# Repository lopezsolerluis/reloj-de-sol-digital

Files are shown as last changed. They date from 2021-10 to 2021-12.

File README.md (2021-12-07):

# reloj de sol digital

En el que damos cuenta de las discusiones, epifanías y callejones sin salida de Antonia y Cecilia.

## Un posible juego de STLs

Para quien quiera imprimir una posible versión del reloj sin necesidad de usar OpenSCAD, Cecilia y Antonia me permitieron ofrecer la que pueden encontrar en este mismo repositorio en su correspondiente carpeta.

La base y el cabezal son diseño de **Ramiro Gabriel Arambarri**.

###  _Non est ad astra mollis e terris via_

La frase que adorna el reloj es de Séneca el joven, y también nos fue acercada por Ramiro. No puedo imaginar una leyenda más apropiada para nuestro curso... :)

### Armado

Las imágenes creo que despejan cualquier duda acerca del armado del reloj.

Las tolerancias de los orificios y encastres fueron pensadas para mi impresora 3D; es posible que quien confíe en los STLs ofrecidos deba apelar a los servicios de las limas y los pegamentos. ;)

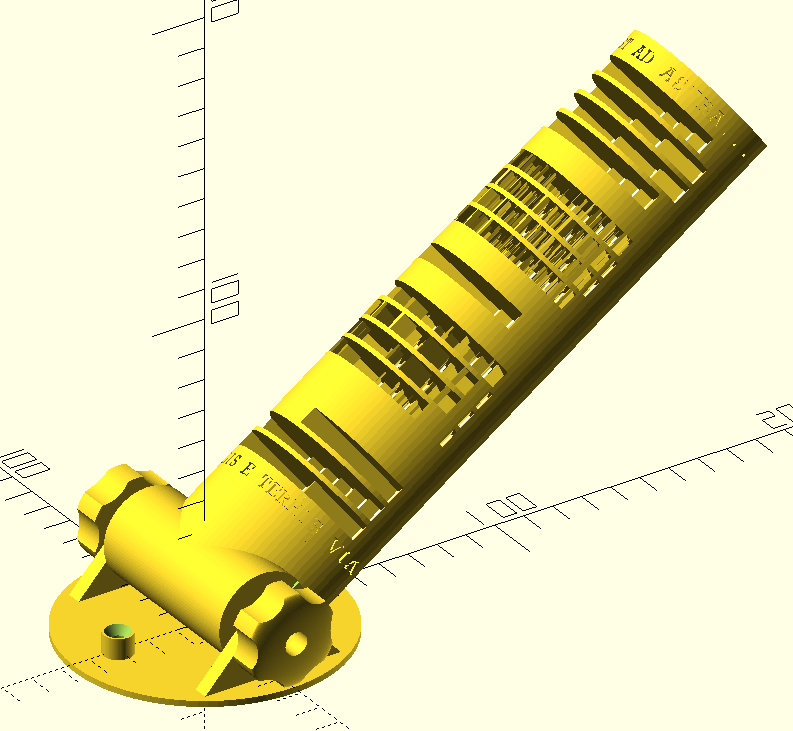
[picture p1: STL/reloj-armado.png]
Reloj Armado

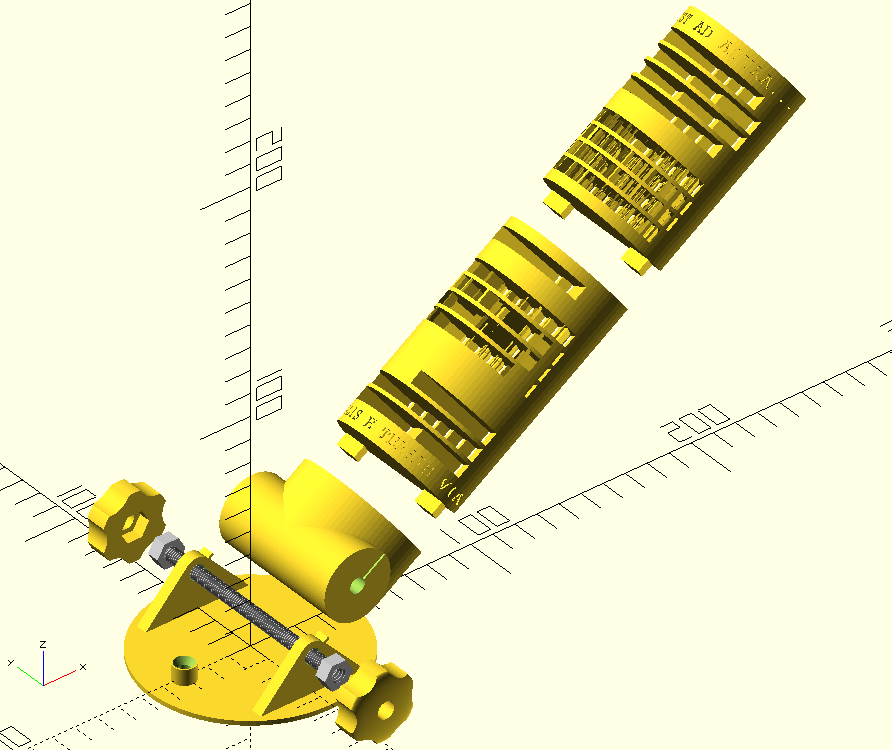
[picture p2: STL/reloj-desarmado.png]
Reloj Desarmado


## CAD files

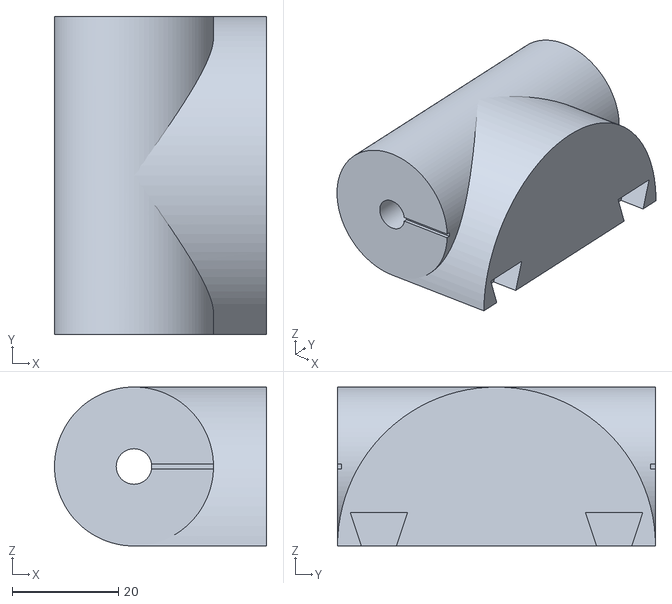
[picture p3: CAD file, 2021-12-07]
STL/cabezal.stl
40.0 x 60.0 x 30.0

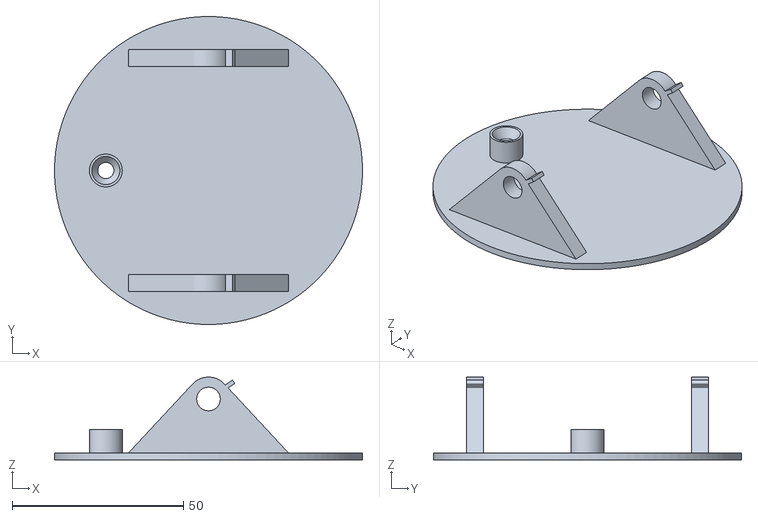
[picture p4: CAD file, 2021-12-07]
STL/base.stl
90.0 x 90.0 x 24.2

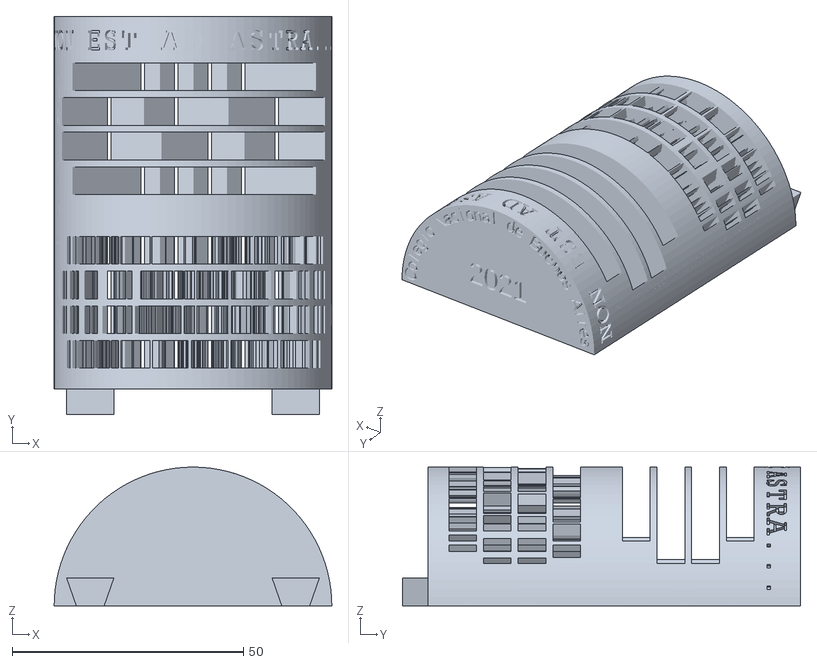
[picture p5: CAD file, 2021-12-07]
STL/reloj-minutos.stl
60.0 x 86.0 x 30.0

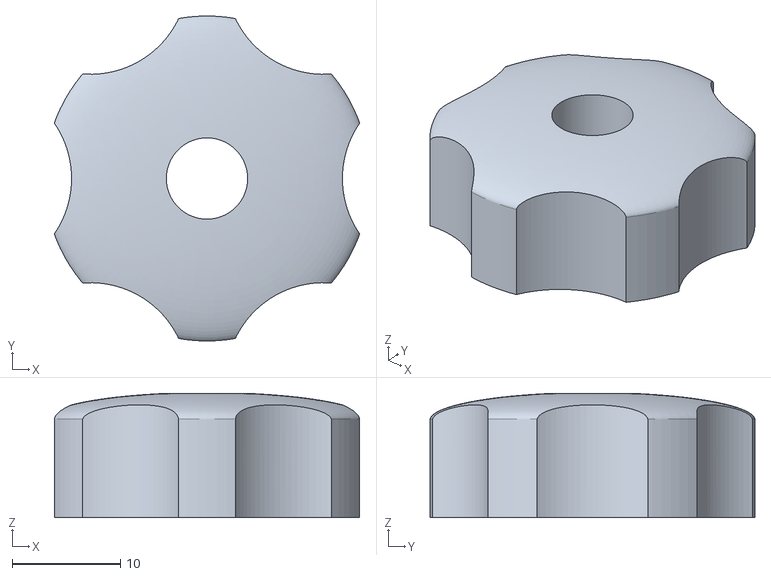
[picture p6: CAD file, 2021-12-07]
STL/perillax2.stl
28.2 x 30.0 x 11.5

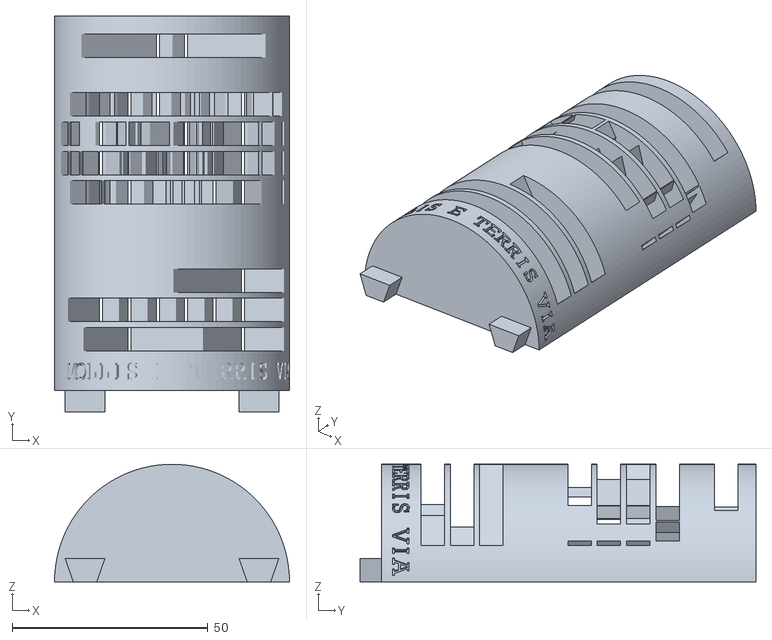
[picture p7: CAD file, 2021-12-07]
STL/reloj-horas.stl
60.0 x 101.0 x 30.0

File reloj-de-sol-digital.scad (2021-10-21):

$fn=100;

module semicilindro(h,r,center=false){
  difference(){
    cylinder(h=h,r=r,center=center);
    translate([-2*r,0,-h])
      cube([4*r,2*r,3*h]);
  }
}

hemisferio="sur";
texto_1 = "Ab Revolutionibus Astri...";
texto_2 = "...Girum Orbis Noscimus";
alto_pixel = .75;
ancho_pixel = 6;
delta_alto  = 6.5;
delta_ancho = 1.5;
borde = 10;
radio_semicilindro = 30;
H = radio_semicilindro+10;
largo_reloj = 21*ancho_pixel + 20*delta_ancho + 2*borde;

function alfa_sur(hora)=270-15*hora; 
function alfa_norte(hora)=15*hora-90;

function alfa(hora)=
  hemisferio=="sur" ? alfa_sur(hora) : alfa_norte(hora);

function truncate(n)=
  n<0 ? ceil(n) : floor(n);

// p es la posicion del digito a obtener: 
// 0 para las unidades, 1 para las decenas, etc.
function n_a_digito(n,p)= 
  truncate(n/pow(10,p))%10;

module haz_de_sol(alfa1,alfa2){
  alfa_min=min(alfa1,alfa2);
  alfa_max=max(alfa1,alfa2);
  D1=H/tan(alfa_min);
  D2=H/tan(alfa_max);
  vertices=[[-alto_pixel/2,0],
            [D2-alto_pixel/2,H],
            [D1+alto_pixel/2,H],
            [alto_pixel/2,0]];
  rotate ([90,0,0])
    linear_extrude(ancho_pixel,center=true)
      polygon(vertices);
}

digitos = [
[[0, 1 ,1, 0], // cero
 [1, 0, 0, 1],
 [1, 0, 1, 1],
 [1, 1, 0, 1],
 [1, 0, 0, 1],
 [0, 1, 1, 0]],
[[0, 1, 0 ,0], // uno
 [1, 1, 0, 0],
 [0, 1, 0, 0],
 [0, 1, 0, 0],
 [0, 1, 0, 0],
 [1, 1, 1, 0]],
[[0, 1 ,1, 0], // dos
 [1, 0, 0, 1],
 [0, 0, 0, 1],
 [0, 1, 1, 0],
 [1, 0, 0, 0],
 [1, 1, 1, 1]],
[[0, 1 ,1, 0],  // tres
 [1, 0, 0, 1],
 [0, 0, 1, 1],
 [0, 0, 0, 1],
 [1, 0, 0, 1],
 [0, 1, 1, 0]],
[[1, 0 ,0, 1],  //cuatro
 [1, 0, 0, 1],
 [1, 0, 0, 1],
 [1, 1, 1, 1],
 [0, 0, 0, 1],
 [0, 0, 0, 1]],
[[1, 1 ,1, 1],  // cinco
 [1, 0, 0, 0],
 [1, 1, 1, 0],
 [0, 0, 0, 1],
 [0, 0, 0, 1],
 [1, 1, 1, 0]],
[[0, 1 ,1, 0],  // seis
 [1, 0, 0, 0],
 [1, 1, 1, 0],
 [1, 0, 0, 1],
 [1, 0, 0, 1],
 [0, 1, 1, 0]],
[[1, 1 ,1, 0],  // siete
 [0, 0, 1, 0],
 [0, 1, 0, 0],
 [0, 1, 0, 0],
 [0, 1, 0, 0],
 [0, 1, 0, 0]],
[[0, 1 ,1, 0],  // ocho
 [1, 0, 0, 1],
 [0, 1, 1, 0],
 [1, 0, 0, 1],
 [1, 0, 0, 1],
 [0, 1, 1, 0]],
[[0, 1 ,1, 0],  // nueve
 [1, 0, 0, 1],
 [1, 0, 0, 1],
 [0, 1, 1, 1],
 [0, 0, 0, 1],
 [0, 1, 1, 0]]];
 
module digito(numero,alfa1,alfa2){
  for(i=[0:5],j=[0:3]){
    digito=digitos[numero];
    if(digito[i][j]==1){
      x=(i-2.5)*(alto_pixel+delta_alto);
      y=(j-1.5)*(ancho_pixel+delta_ancho);
      translate([x,y,-0.01])
        haz_de_sol(alfa1,alfa2);
    }
  }
}

module hora_solar(horas, 
                  minutos){
  hora=horas+minutos/60;
  assert(hora>6 && hora<18,"La hora debe encontrarse entre las 6:00 y las 18:00.");
  alfa=alfa(hora);
  hora_decenas=n_a_digito(horas,1);
  hora_unidades=n_a_digito(horas,0);
  minuto_decenas=n_a_digito(minutos,1);
  minuto_unidades=n_a_digito(minutos,0);
                    
  delta_y=ancho_pixel+delta_ancho;
  // horas    
  if (hora_decenas != 0)
    translate([0,-8.5*delta_y,0])
      digito(hora_decenas,alfa,alfa);
  translate([0,-3.5*delta_y,0])
    digito(hora_unidades,alfa,alfa);  
  // minutos
  translate([0,3.5*delta_y,0])
    digito(minuto_decenas,alfa,alfa);
  translate([0,8.5*delta_y,0])
    digito(minuto_unidades,alfa,alfa);  
  // separador
  separador(alfa,alfa);
}

module separador(alfa1,alfa2){
  for(i=[-1,1])
    translate([i*0.5*(alto_pixel+delta_alto), 0, -.01])
      haz_de_sol(alfa1,alfa2);
}
 
module cuerpo(largo){
  rotate([-90,0,0])
    semicilindro(largo, radio_semicilindro, center=true);  
}

/* Reloj de Sol de algunas horas puntuales.
   'vector_horas' es un vector con las horas y minutos que el usuario desea mostrar; por ej.: [[12,00], [7,13], [16,23]] representa las 12:00, 7:13 y 16:23.
*/
module reloj_de_sol_discreto(vector_horas){
  difference(){
    cuerpo(largo_reloj);    
    for(hora_minutos=vector_horas){
      hora=hora_minutos[0];
      minutos=hora_minutos[1];
      hora_solar(hora,minutos);    
    }
  }
}

/*
  Reloj de Sol con las horas desde las 9:00 a las 15:10,
  en intervalos de 20 minutos.
*/
module reloj_de_sol_continuo(){
  delta_y=ancho_pixel+delta_ancho;
  difference(){
    cuerpo(largo_reloj);    
    // unidades de minuto
    translate([0,8.5*delta_y,0])
      digito(0,alfa(9),alfa(15+10/60));  
    // decenas de minuto
    translate([0,3.5*delta_y,0]){
      for(hora=[9:14],
          minutos=[0,20,40]){
            minuto_decenas=n_a_digito(minutos,1);
            digito(minuto_decenas,
                   alfa(hora+minutos/60),
                   alfa(hora+(minutos+10)/60));
            }
       digito(0,alfa(15),alfa(15+10/60));
       }                    
    // separador
    separador(alfa(9),alfa(15+10/60));      
    // unidades de hora       
    translate([0,-3.5*delta_y,0])
      for(hora=[9:15]){
        hora_unidades=n_a_digito(hora,0);
        digito(hora_unidades,
               alfa(hora),
               alfa(hora<15?hora+50/60:hora+10/60));
      }
    // decenas de hora
    translate([0,-8.5*delta_y,0])
      digito(1,alfa(10),alfa(15+10/60));    
  }
}

module texto_circular(texto, size, espesor, radio, angulo){
  n=len(texto)-1;
  delta_alfa=angulo/n;
  for(i=[0:n])
    rotate([0,0,delta_alfa*i-angulo/2])    
      translate([radio,0,0])
        rotate([90,0,90])
          linear_extrude(espesor)
            text(texto[i], size=size, font="DejaVu Sans:style=Book", halign="center");
}

/* Crea un reloj de Sol en función del valor de 'vector_horas'.
   Ver comentarios en los módulos
   'reloj_de_sol_continuo' y 'reloj_de_sol_discreto'.
*/
module reloj_de_sol(vector_horas){
  difference(){
    // Reloj
    if(vector_horas==undef)
      reloj_de_sol_continuo();
    else
      reloj_de_sol_discreto(vector_horas);
    // Textos
    translate([0,largo_reloj/2-borde+2.5,0])
      rotate([0,-90,-90])
        texto_circular(texto_1,5,2, radio_semicilindro-1.2,165);
    translate([0,-largo_reloj/2+2.5,0])
      rotate([0,-90,-90])
        texto_circular(texto_2,5,2, radio_semicilindro-1.9,165);
  }
}

reloj_de_sol();

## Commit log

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2021-06-10 Segunda versión del semicilindro: agregado del parámetro 'center'
    [reloj-de-sol-digital.scad]
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2021-06-23 Leve cambio a la primera versión del primer rayo de Sol
    [reloj-de-sol-digital.scad]
2021-07-01 Primera extrusión y rotación del rayo de Sol
    [reloj-de-sol-digital.scad]
2021-07-01 Versión de Antonia del rayo de Sol extrudido y rotado
    [reloj-de-sol-digital.scad]
2021-07-01 Primera versión del digito solar: la matriz completa
    [reloj-de-sol-digital.scad]
2021-07-01 Segunda versión del digito solar: la matriz centrada
    [reloj-de-sol-digital.scad]
2021-07-01 Tercera versión del digito solar: la matriz centrada usando un factor común
    [reloj-de-sol-digital.scad]
2021-07-01 Cuarta versión del digito solar: la matriz descendida 0.01 para evitar el error en el difference()
    [reloj-de-sol-digital.scad]
2021-08-09 La solución de Cecilia para la conformación de cada dígito.
    [reloj-de-sol-digital.scad]
2021-08-09 La manera de Cecilia, usando la sintaxis 'vector.x' y 'vector.y'.
    [reloj-de-sol-digital.scad]
2021-08-09 La solución de Antonia a la conformación de cada dígito.
    [reloj-de-sol-digital.scad]
2021-08-26 Las funciones que calculan el ángulo alfa en función de la hora del día, para ambos hemisferios terrestres.
    [reloj-de-sol-digital.scad]
2021-08-26 La función que calcula el ángulo alfa en función de la hora del día y el hemisferio terrestre elegido previamente por el usuario mediante una variable inicial.
    [reloj-de-sol-digital.scad]
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2021-08-31 El módulo 'hora_solar' ya sabe extraer los dígitos de la hora y los minutos.
    [reloj-de-sol-digital.scad]
2021-09-08 Primera versión del separador de horas y minutos
    [reloj-de-sol-digital.scad]
2021-09-08 Segunda versión del separador de horas y minutos
    [reloj-de-sol-digital.scad]
2021-09-08 Se añade un módulo que abstrae la idea del 'cuerpo' del reloj
    [reloj-de-sol-digital.scad]
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2021-09-08 Se modifica el módulo 'hora_solar' para que no muestre el '0' inicial en las horas previas a las 10:00.
    [reloj-de-sol-digital.scad]
2021-09-08 El separador pasa a formar parte del módulo 'hora_solar'.
    [reloj-de-sol-digital.scad]
2021-09-18 Se crea el módulo 'reloj-de-sol', y el largo del mismo está parametrizado.
    [reloj-de-sol-digital.scad]
2021-09-18 Primera versión (ingenua y fallida) del reloj de Sol, con todas las horas desde las 6:00 a las 18:00.
    [reloj-de-sol-digital.scad]
2021-09-18 Primer uso de 'assert' por parte de Cecilia, para evitar los ángulos extremos.
    [reloj-de-sol-digital.scad]
2021-09-18 Cecilia traslada el 'assert' dentro del módulo 'hora_solar'.
    [reloj-de-sol-digital.scad]
2021-09-18 Se impiden asimismo las horas fuera del intervalo entre las 6:00 y las 18:00.
    [reloj-de-sol-digital.scad]
2021-09-18 Cecilia confirma que el reloj aún funciona para las 12:00.
    [reloj-de-sol-digital.scad]
2021-09-24 Se cambió al alto de los pixeles de 2 a 1.6
    [reloj-de-sol-digital.scad]
2021-09-27 Versión de Cecilia de todas las horas separados por 20 minutos desde las 6:20 a las 17:40.
    [reloj-de-sol-digital.scad]
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2021-09-27 Reescritura de 'digito' para que trabaje con haz_de_sol.
    [reloj-de-sol-digital.scad]
2021-09-27 Primera modificación de hora_solar para que trabaje con haz_de_sol.
    [reloj-de-sol-digital.scad]
2021-09-27 Modificación del 'separador' para que trabaje con haz_de_sol.
    [reloj-de-sol-digital.scad]
2021-09-27 Modificación de hora_solar para que trabaje con el nuevo 'separador'.
    [reloj-de-sol-digital.scad]
2021-09-27 Antonia y Cecilia comprueban que todo sigue funcionando como antes luego de la refactorización.
    [reloj-de-sol-digital.scad]
2021-10-04 Se crea el módulo 'reloj_de_sol_discreto', capaz de mostrar horas particulares.
    [reloj-de-sol-digital.scad]
2021-10-04 Primera versión del 'reloj_de_sol_continuo', con las unidades de los minutos.
    [reloj-de-sol-digital.scad]
2021-10-04 Se corrige el bug del módulo 'haz_de_sol', referente al cruce de los ángulos del polígono que define el haz.
    [reloj-de-sol-digital.scad]
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2021-10-04 Se agregan las unidades de las horas a 'reloj_solar_continuo'.
    [reloj-de-sol-digital.scad]
2021-10-04 Antonia y Cecilia se resignan a un alto_pixel=0.75 y a mostrar las horas desde las 9:00 a las 15:10.
    [reloj-de-sol-digital.scad]
2021-10-04 Cecilia adecua los minutos y el separador al intervalo 6:00-15:10.
    [reloj-de-sol-digital.scad]
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2021-10-18 El módulo 'reloj_de_sol' crea un reloj de Sol continuo o discreto, dependiendo de si se pasa o no como parámetro un vector con horas puntuales.
    [reloj-de-sol-digital.scad]
2021-10-18 Antonia y Cecilia se deciden por una de las dos posibles implementaciones de la creación del haz del luz. Las dos eran igual de veloces (y eficaces).
    [reloj-de-sol-digital.scad]
2021-10-18 Módulo 'texto_circular' añadido. El mismo permite desplegar un texto a lo largo de un arco circular, de forma que las letras estén orientadas con su dorso dirigido al centro y paralelamente al eje de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
    [reloj-de-sol-digital.scad]
2021-10-18 Se agregan como variables, al principio, los textos de los bordes del reloj.
    [reloj-de-sol-digital.scad]
2021-10-21 Cecilia y Antonia enriquecen los bordes del reloj con una adecuada leyenda.
    [reloj-de-sol-digital.scad]
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
